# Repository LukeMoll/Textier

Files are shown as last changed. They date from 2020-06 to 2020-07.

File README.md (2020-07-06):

# Textier
_Low-cost mechanical macro pad_

## Known issues
### "Blackpill" board
 - STM32F411CE only has two USB endpoints - not enough for CircuitPython's MSC & CDC in addition to HID and/or AUDIO (MIDI)
     - Can remove MSC and use [ampy](https://github.com/scientifichackers/ampy) instead
 - Some LED IO shared with optional flash memory footprint
 - Wide DSA profile keycaps conflict with the blackpill board edge when fully inserted in socket
 
Mostly solved by [greenpill](https://github.com/Stary2001/greenpill)

### Blackpill CircuitPython port
 - `rotaryio` [not implemented in STM port](https://github.com/adafruit/circuitpython/issues/2544)
 - `C15` shown as "in use" when try to construct `NeoPixel(board.C15, 9)`

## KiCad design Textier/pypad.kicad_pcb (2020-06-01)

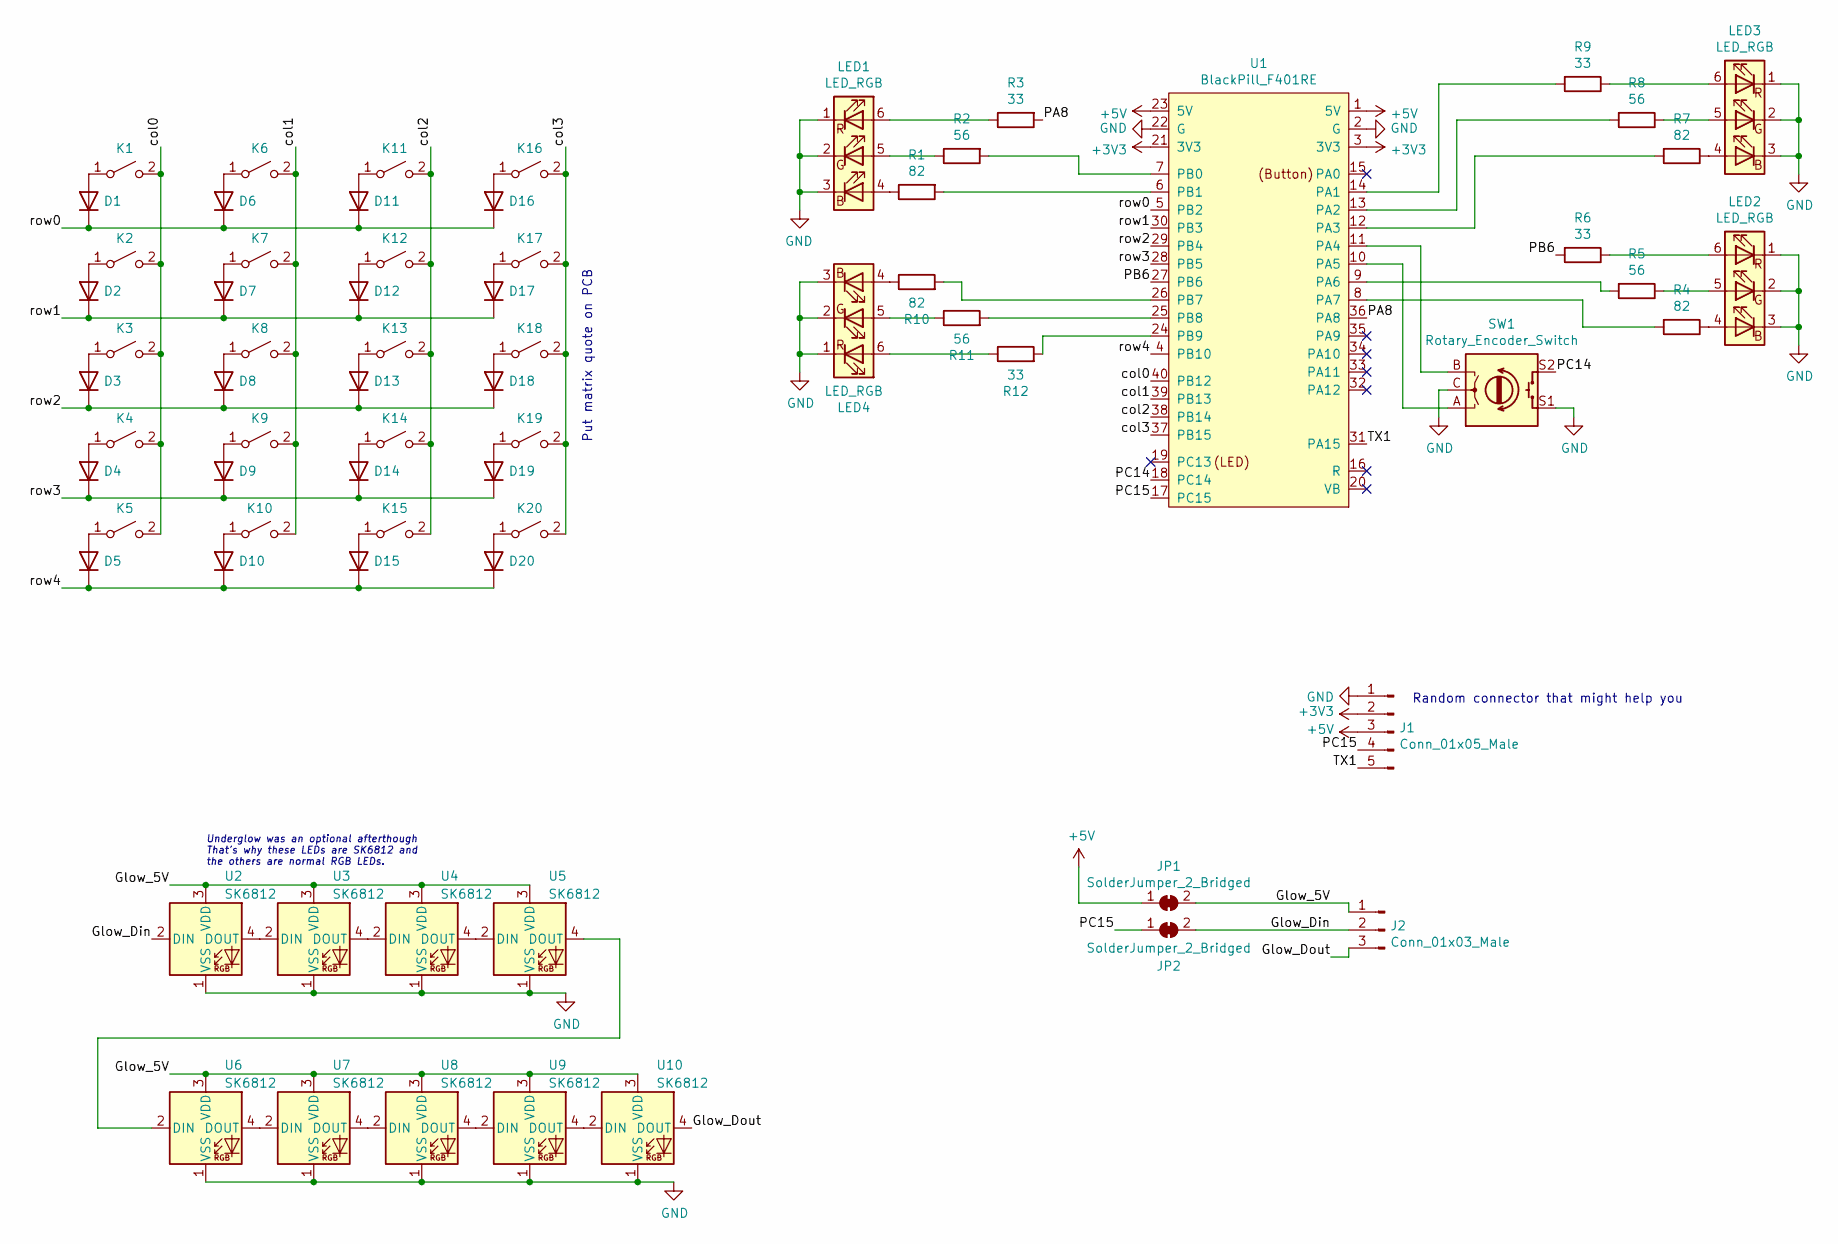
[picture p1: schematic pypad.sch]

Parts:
D1, D2, D3, D4, D5, D6, D7, D8, D9, D10, D11, D12, D13, D14, D15, D16, D17, D18, D19, D20: 1N4148; D_DO-35_SOD27_P7.62mm_Horizontal
J1: Conn_01x05_Male; PinHeader_1x05_P2.54mm_Vertical
J2: Conn_01x03_Male; PinHeader_1x03_P2.54mm_Vertical
JP1, JP2: SolderJumper_2_Bridged; SolderJumper-2_P1.3mm_Bridged2BarCuttable_RoundedPad1.0x1.5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
K1, K2, K3, K4, K5, K6, K7, K8, K9, K10, K11, K12, K13, K14, K15, K16, K17, K18, K19, K20: SW_SPST; SW_Cherry_MX_1.00u_PCB
LED1, LED2, LED3, LED4: LED_RGB; LED_RGB_PLCC-6
R1, R4, R7, R10: 82; R_0805_2012Metric_Pad1.15x1.40mm_HandSolder
R2, R5, R8, R11: 56; R_0805_2012Metric_Pad1.15x1.40mm_HandSolder
R3, R6, R9, R12: 33; R_0805_2012Metric_Pad1.15x1.40mm_HandSolder
SW1: Rotary_Encoder_Switch; RotaryEncoder_Bourns_PEC16-4-Switch_Vertical_H20mm
U1: BlackPill_F401RE
U2, U3, U4, U5, U6, U7, U8, U9, U10: SK6812; LED_SK6812_PLCC4_5.0x5.0mm_P3.2mm

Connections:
+3V3: J1.2, U1.3 (3V3), U1.21 (3V3)
+5V: J1.3, JP1.1 (A), U1.1 (5V), U1.23 (5V)
/Glow_5V: J2.1, JP1.2 (B), U2.3 (VDD), U3.3 (VDD), U4.3 (VDD), U5.3 (VDD), U6.3 (VDD), U7.3 (VDD), U8.3 (VDD), U9.3 (VDD), U10.3 (VDD)
/Glow_Din: J2.2, JP2.2 (B), U2.2 (DIN)
/Glow_Dout: J2.3, U10.4 (DOUT)
/PA8: R3.2, U1.36 (PA8)
/PB6: R6.2, U1.27 (PB6)
/PC14: SW1.S2, U1.18 (PC14)
/PC15: J1.4, JP2.1 (A), U1.17 (PC15)
/TX1: J1.5, U1.31 (PA15)
/col0: K1.2 (B), K2.2 (B), K3.2 (B), K4.2 (B), K5.2 (B), U1.40 (PB12)
/col1: K6.2 (B), K7.2 (B), K8.2 (B), K9.2 (B), K10.2 (B), U1.39 (PB13)
/col2: K11.2 (B), K12.2 (B), K13.2 (B), K14.2 (B), K15.2 (B), U1.38 (PB14)
/col3: K16.2 (B), K17.2 (B), K18.2 (B), K19.2 (B), K20.2 (B), U1.37 (PB15)
/row0: D1.1 (K), D6.1 (K), D11.1 (K), D16.1 (K), U1.5 (PB2)
/row1: D2.1 (K), D7.1 (K), D12.1 (K), D17.1 (K), U1.30 (PB3)
/row2: D3.1 (K), D8.1 (K), D13.1 (K), D18.1 (K), U1.29 (PB4)
/row3: D4.1 (K), D9.1 (K), D14.1 (K), D19.1 (K), U1.28 (PB5)
/row4: D5.1 (K), D10.1 (K), D15.1 (K), D20.1 (K), U1.4 (PB10)
GND: J1.1, LED1.1 (RK), LED1.2 (GK), LED1.3 (BK), LED2.1 (RK), LED2.2 (GK), LED2.3 (BK), LED3.1 (RK), LED3.2 (GK), LED3.3 (BK), LED4.1 (RK), LED4.2 (GK), LED4.3 (BK), SW1.C, SW1.S1, U1.2 (G), U1.22 (G), U2.1 (VSS), U3.1 (VSS), U4.1 (VSS), U5.1 (VSS), U6.1 (VSS), U7.1 (VSS), U8.1 (VSS), U9.1 (VSS), U10.1 (VSS)
unnamed: D1.2 (A), K1.1 (A)
unnamed: D2.2 (A), K2.1 (A)
unnamed: D3.2 (A), K3.1 (A)
unnamed: D4.2 (A), K4.1 (A)
unnamed: D5.2 (A), K5.1 (A)
unnamed: D6.2 (A), K6.1 (A)
unnamed: D7.2 (A), K7.1 (A)
unnamed: D8.2 (A), K8.1 (A)
unnamed: D9.2 (A), K9.1 (A)
unnamed: D10.2 (A), K10.1 (A)
unnamed: D11.2 (A), K11.1 (A)
unnamed: D12.2 (A), K12.1 (A)
unnamed: D13.2 (A), K13.1 (A)
unnamed: D14.2 (A), K14.1 (A)
unnamed: D15.2 (A), K15.1 (A)
unnamed: D16.2 (A), K16.1 (A)
unnamed: D17.2 (A), K17.1 (A)
unnamed: D18.2 (A), K18.1 (A)
unnamed: D19.2 (A), K19.1 (A)
unnamed: D20.2 (A), K20.1 (A)
unnamed: LED1.4 (BA), R1.1
unnamed: LED1.5 (GA), R2.1
unnamed: LED1.6 (RA), R3.1
unnamed: LED2.4 (BA), R4.1
unnamed: LED2.5 (GA), R5.1
unnamed: LED2.6 (RA), R6.1
unnamed: LED3.4 (BA), R7.1
unnamed: LED3.5 (GA), R8.1
unnamed: LED3.6 (RA), R9.1
unnamed: LED4.4 (BA), R10.1
unnamed: LED4.5 (GA), R11.1
unnamed: LED4.6 (RA), R12.1
unnamed: R1.2, U1.6 (PB1)
unnamed: R2.2, U1.7 (PB0)
unnamed: R4.2, U1.8 (PA7)
unnamed: R5.2, U1.9 (PA6)
unnamed: R7.2, U1.12 (PA3)
unnamed: R8.2, U1.13 (PA2)
unnamed: R9.2, U1.14 (PA1)
unnamed: R10.2, U1.26 (PB7)
unnamed: R11.2, U1.25 (PB8)
unnamed: R12.2, U1.24 (PB9)
unnamed: SW1.A, U1.10 (PA5)
unnamed: SW1.B, U1.11 (PA4)
unnamed: U2.4 (DOUT), U3.2 (DIN)
unnamed: U3.4 (DOUT), U4.2 (DIN)
unnamed: U4.4 (DOUT), U5.2 (DIN)
unnamed: U5.4 (DOUT), U6.2 (DIN)
unnamed: U6.4 (DOUT), U7.2 (DIN)
unnamed: U7.4 (DOUT), U8.2 (DIN)
unnamed: U8.4 (DOUT), U9.2 (DIN)
unnamed: U9.4 (DOUT), U10.2 (DIN)

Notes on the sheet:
Random connector that might help you
Put matrix quote on PCB
Underglow was an optional afterthough That's why these LEDs are SK6812 and the others are normal RGB LEDs.

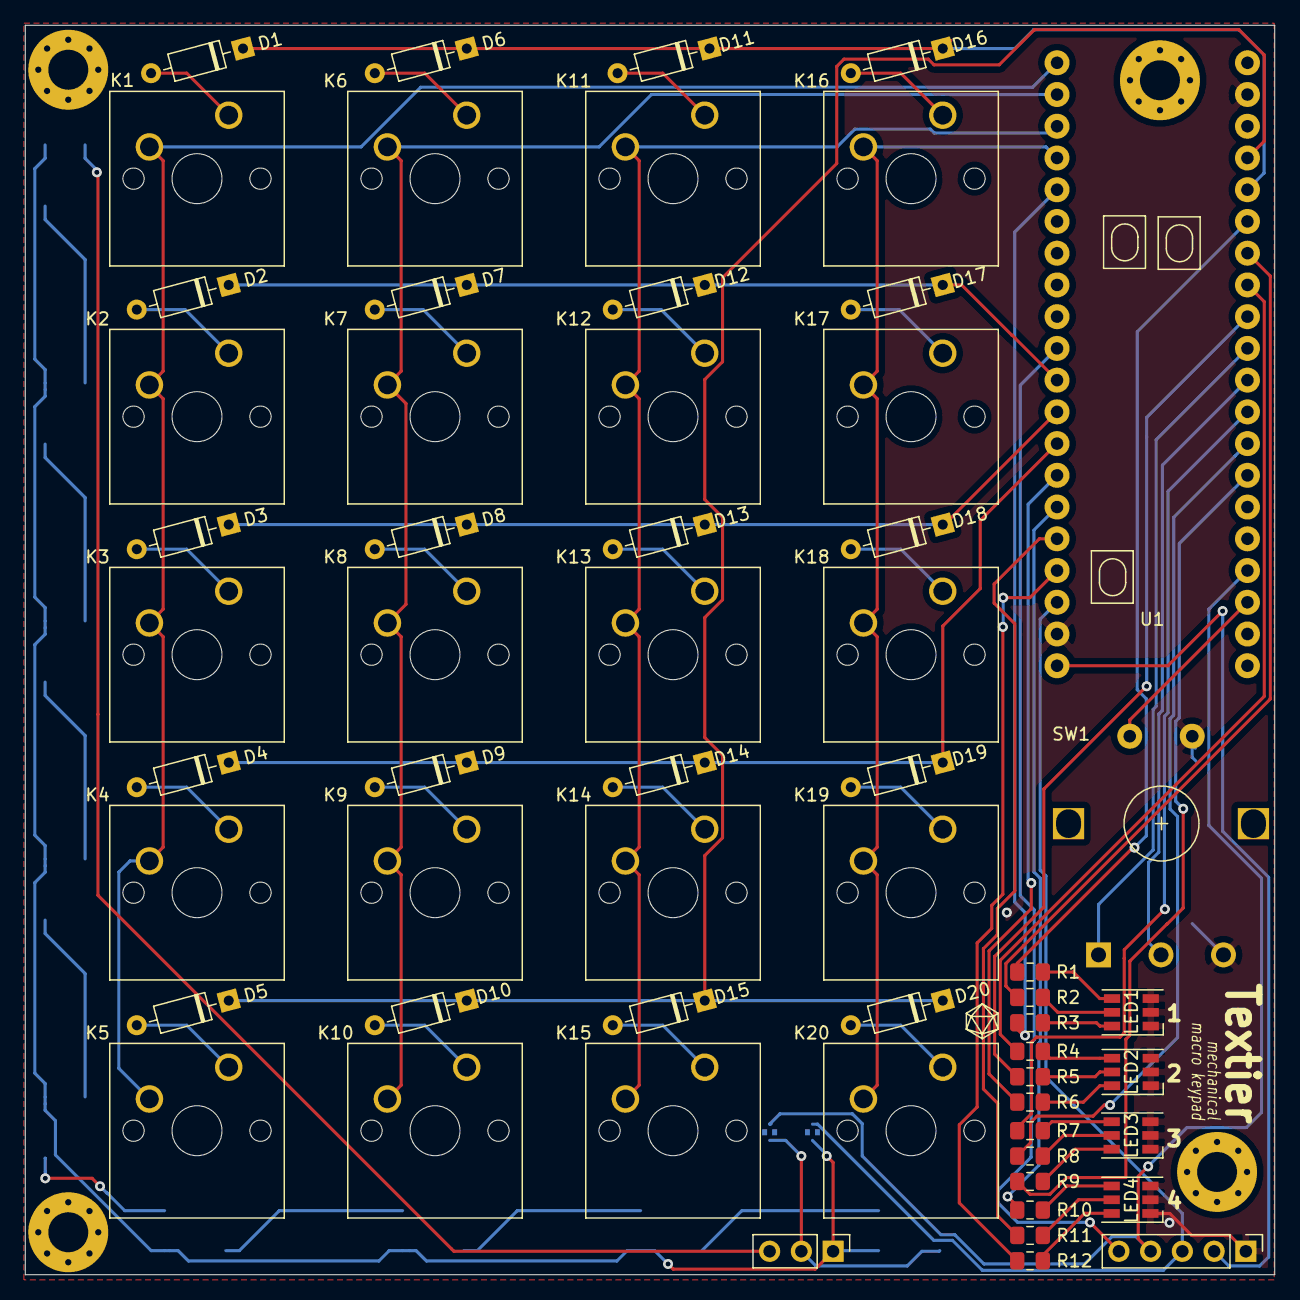
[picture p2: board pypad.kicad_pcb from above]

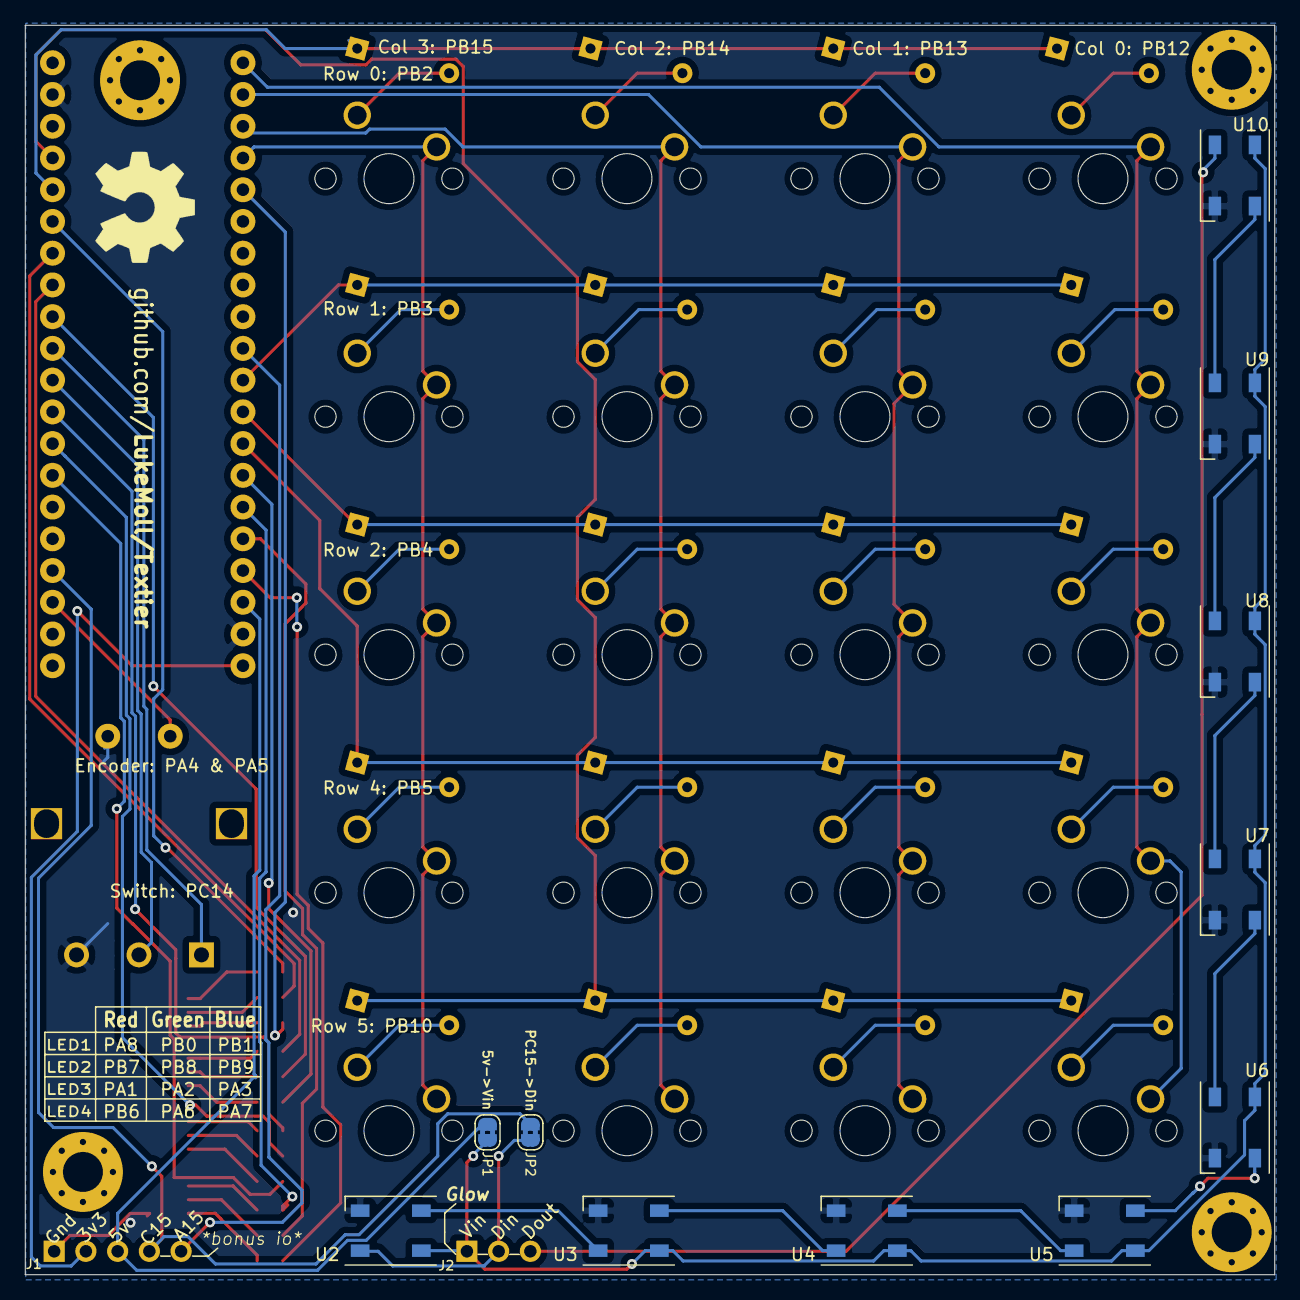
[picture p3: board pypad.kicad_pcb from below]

Board: 2 copper layers, 100.0 x 100.0 mm, 75 parts (11 on the bottom side), 72 nets.

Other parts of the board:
M1, M2, M3, M4: MountingHole_3.2mm_M3_Pad_Via

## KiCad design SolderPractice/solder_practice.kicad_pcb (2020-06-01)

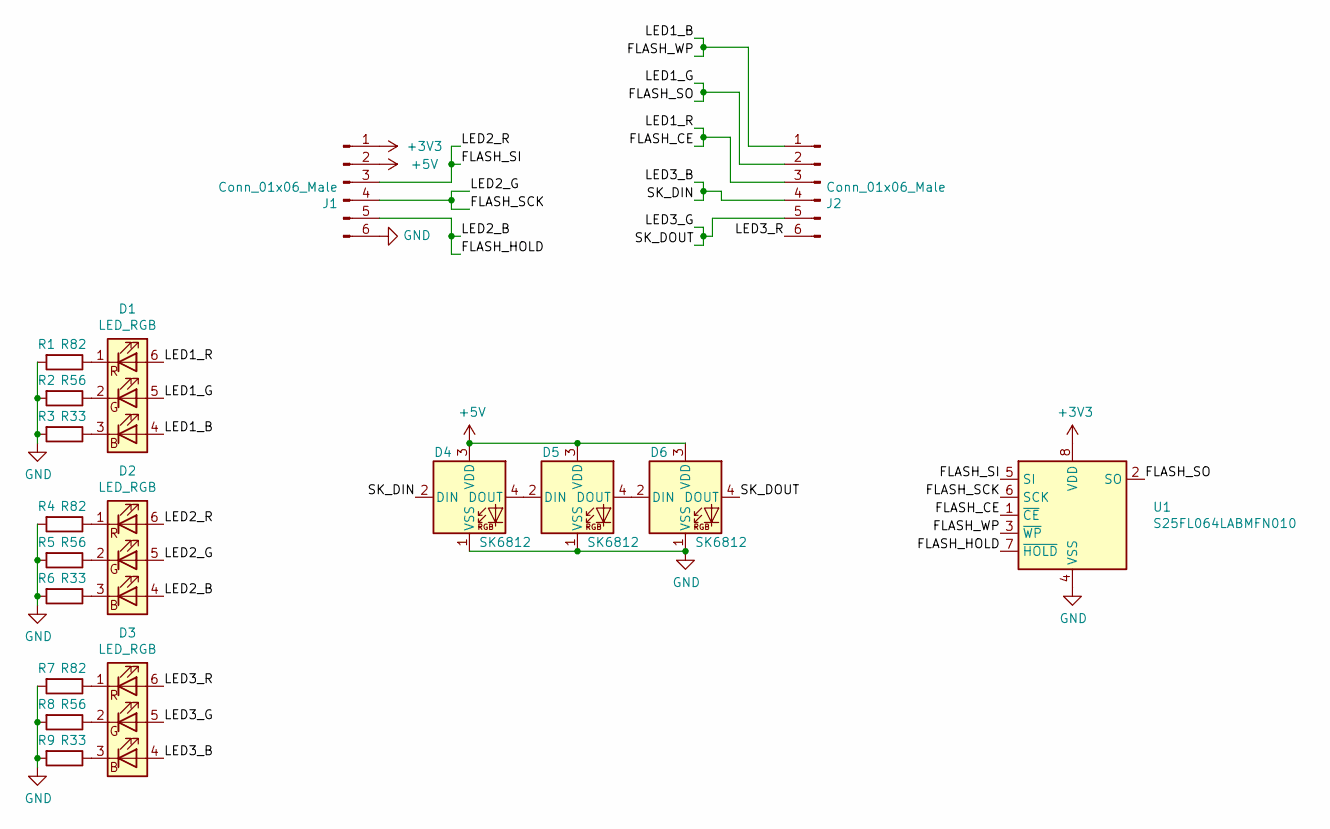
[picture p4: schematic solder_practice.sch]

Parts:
D1, D2, D3: LED_RGB; LED_RGB_PLCC-6
D4, D5, D6: SK6812; LED_SK6812_PLCC4_5.0x5.0mm_P3.2mm
J1, J2: Conn_01x06_Male; PinHeader_1x06_P2.54mm_Vertical
R1, R4, R7: R82; R_0805_2012Metric_Pad1.15x1.40mm_HandSolder
R2, R5, R8: R56; R_0805_2012Metric_Pad1.15x1.40mm_HandSolder
R3, R6, R9: R33; R_0805_2012Metric_Pad1.15x1.40mm_HandSolder
U1: S25FL064LABMFN010; SOIC-8_5.275x5.275mm_P1.27mm

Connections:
+3V3: J1.1, U1.8 (VDD)
+5V: D4.3 (VDD), D5.3 (VDD), D6.3 (VDD), J1.2
/FLASH_CE: D1.6 (RA), J2.3, U1.1 (~CE)
/FLASH_HOLD: D2.4 (BA), J1.5, U1.7 (~HOLD~)
/FLASH_SCK: D2.5 (GA), J1.4, U1.6 (SCK)
/FLASH_SI: D2.6 (RA), J1.3, U1.5 (SI)
/FLASH_SO: D1.5 (GA), J2.2, U1.2 (SO)
/FLASH_WP: D1.4 (BA), J2.1, U1.3 (~WP~)
/LED3_B: D3.4 (BA), D4.2 (DIN), J2.4
/LED3_G: D3.5 (GA), D6.4 (DOUT), J2.5
/LED3_R: D3.6 (RA), J2.6
GND: D4.1 (VSS), D5.1 (VSS), D6.1 (VSS), J1.6, R1.2, R2.2, R3.2, R4.2, R5.2, R6.2, R7.2, R8.2, R9.2, U1.4 (VSS)
unnamed: D1.1 (RK), R1.1
unnamed: D1.2 (GK), R2.1
unnamed: D1.3 (BK), R3.1
unnamed: D2.1 (RK), R4.1
unnamed: D2.2 (GK), R5.1
unnamed: D2.3 (BK), R6.1
unnamed: D3.1 (RK), R7.1
unnamed: D3.2 (GK), R8.1
unnamed: D3.3 (BK), R9.1
unnamed: D4.4 (DOUT), D5.2 (DIN)
unnamed: D5.4 (DOUT), D6.2 (DIN)

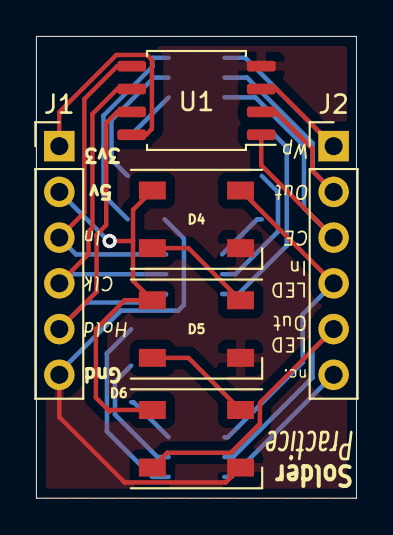
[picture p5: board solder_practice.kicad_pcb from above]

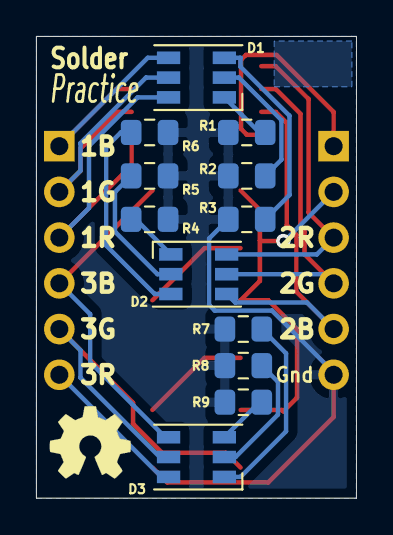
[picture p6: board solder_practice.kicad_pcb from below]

Board: 2 copper layers, 17.8 x 25.7 mm, 18 parts (12 on the bottom side), 23 nets.

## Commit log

2020-05-27 Routing attempt number 2
    [pypad.kicad_pcb, pypad.sch]
2020-05-28 Revision 2
    Moved board around to allow M3 holes, rerouted using freeRouting and manually fixed.
    [pypad.kicad_pcb, pypad.sch]
2020-05-30 Added underglow RGB, misc tweaks
    [pypad.kicad_pcb, pypad.sch]
2020-06-01 Revision 3
    Added rotary encoder footprint, reorganised and rerouted board to accommodate.
    [pypad.kicad_pcb, pypad.sch]
2020-06-01 Reorganised folder structure
    [pypad.kicad_pcb, pypad.sch]
2020-06-01 Added "solder practice" board
    [solder_practice.kicad_pcb, solder_practice.sch]
2020-06-01 Updated BlackPill footprint
    [pypad.kicad_pcb]
2020-06-01 Feedback fixes
    - OSHW logo + github text
    - removed some leftover silkscreen
    [pypad.kicad_pcb]
